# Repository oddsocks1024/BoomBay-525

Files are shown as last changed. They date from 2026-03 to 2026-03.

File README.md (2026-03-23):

# BoomBay 525
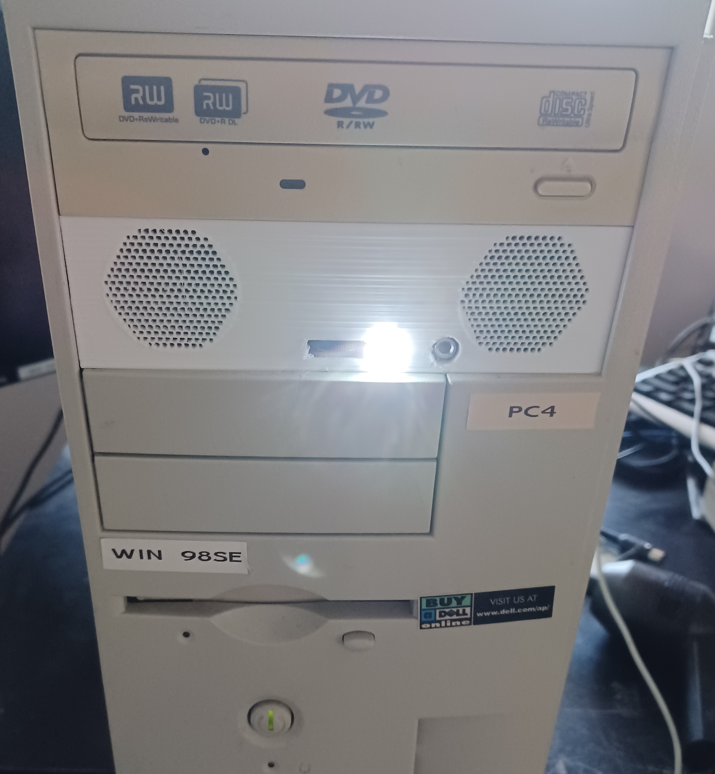
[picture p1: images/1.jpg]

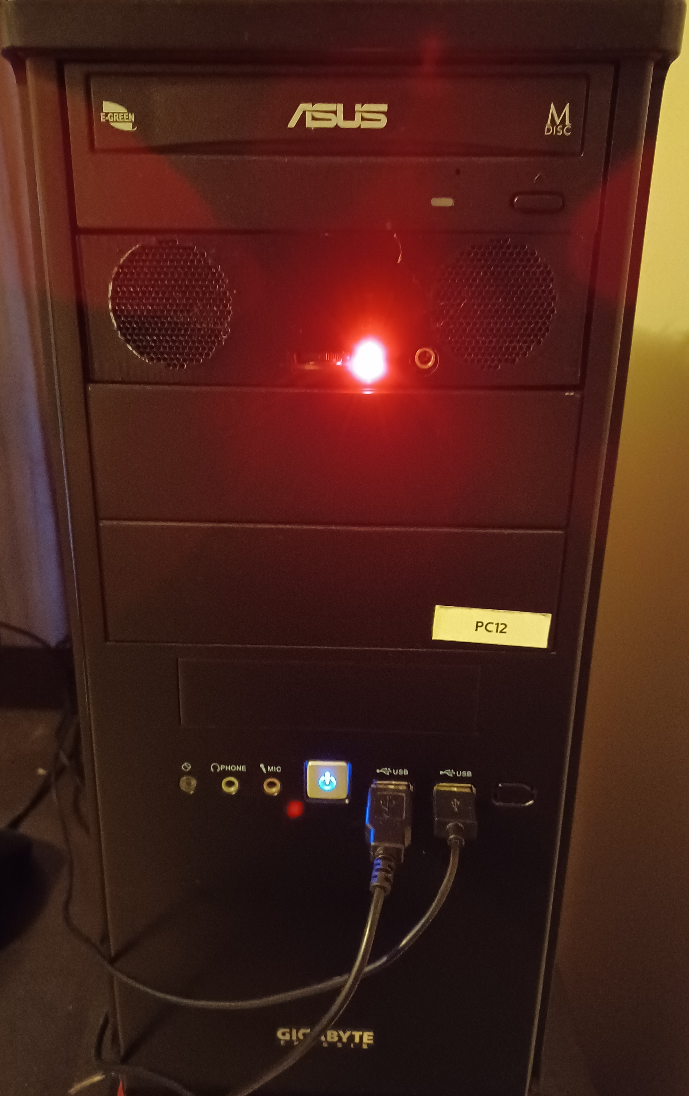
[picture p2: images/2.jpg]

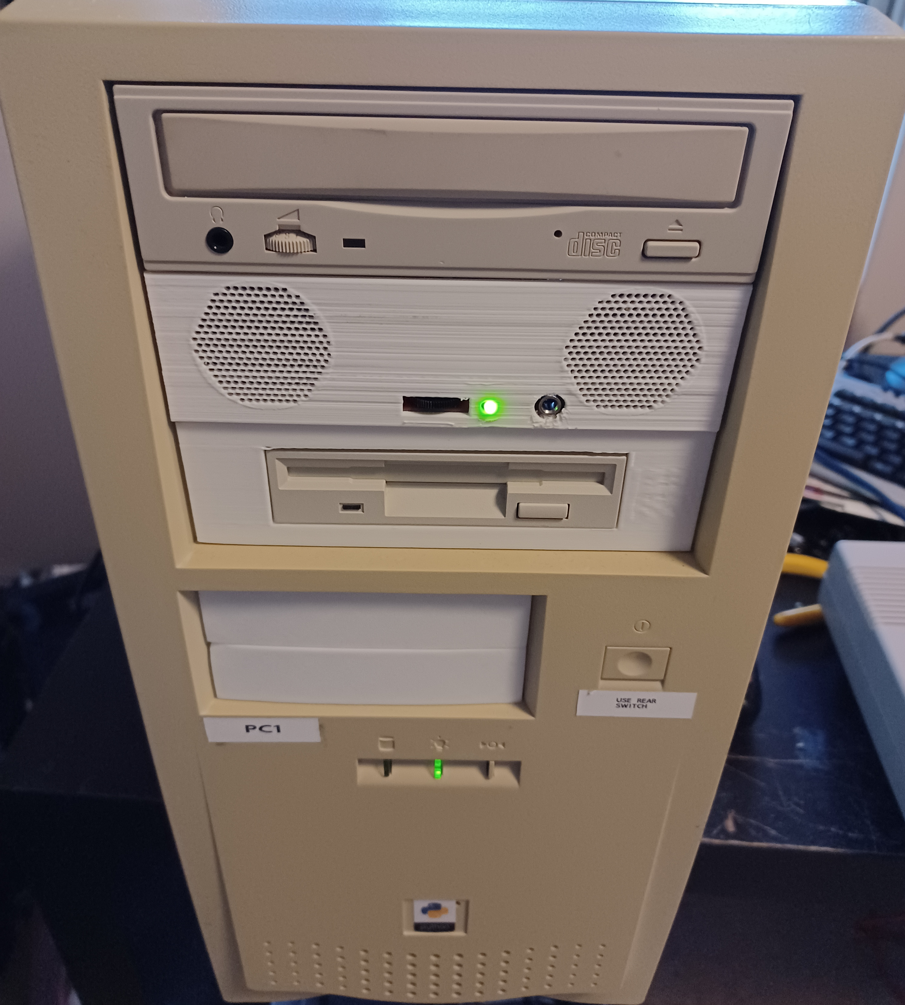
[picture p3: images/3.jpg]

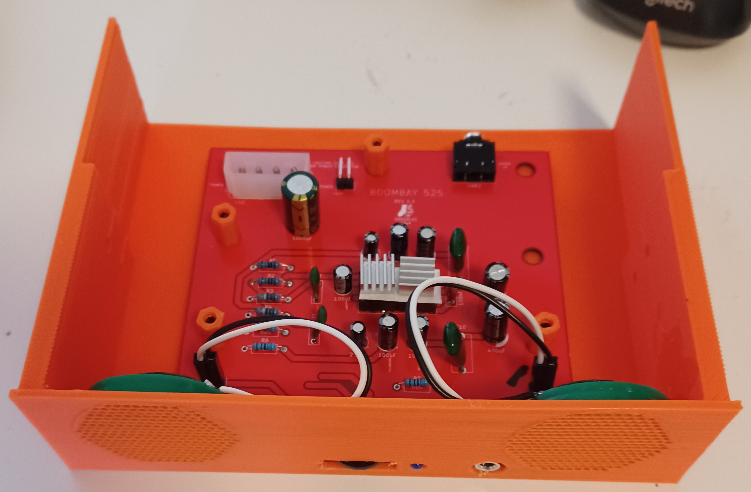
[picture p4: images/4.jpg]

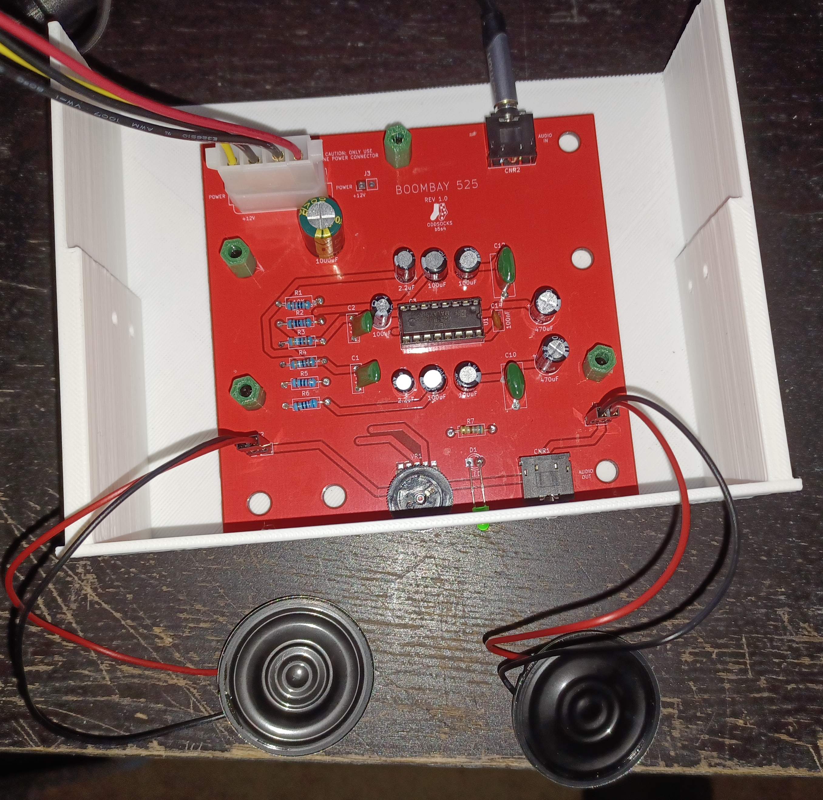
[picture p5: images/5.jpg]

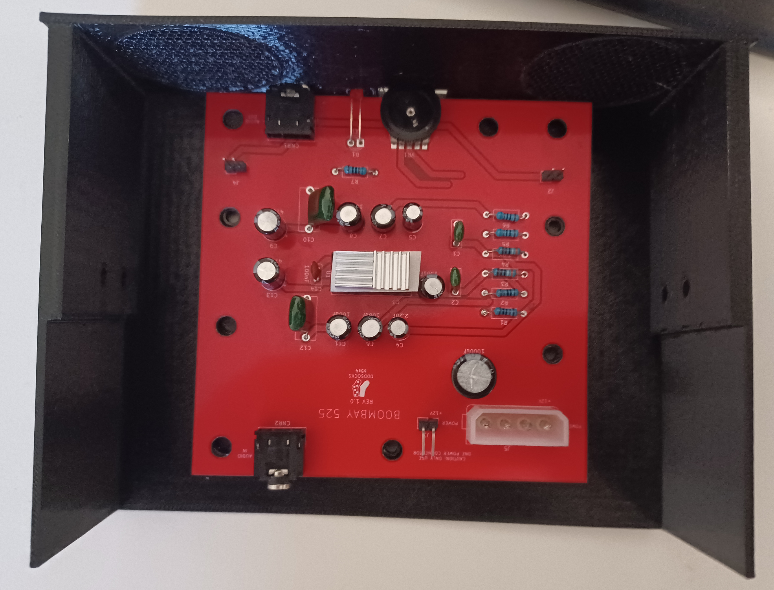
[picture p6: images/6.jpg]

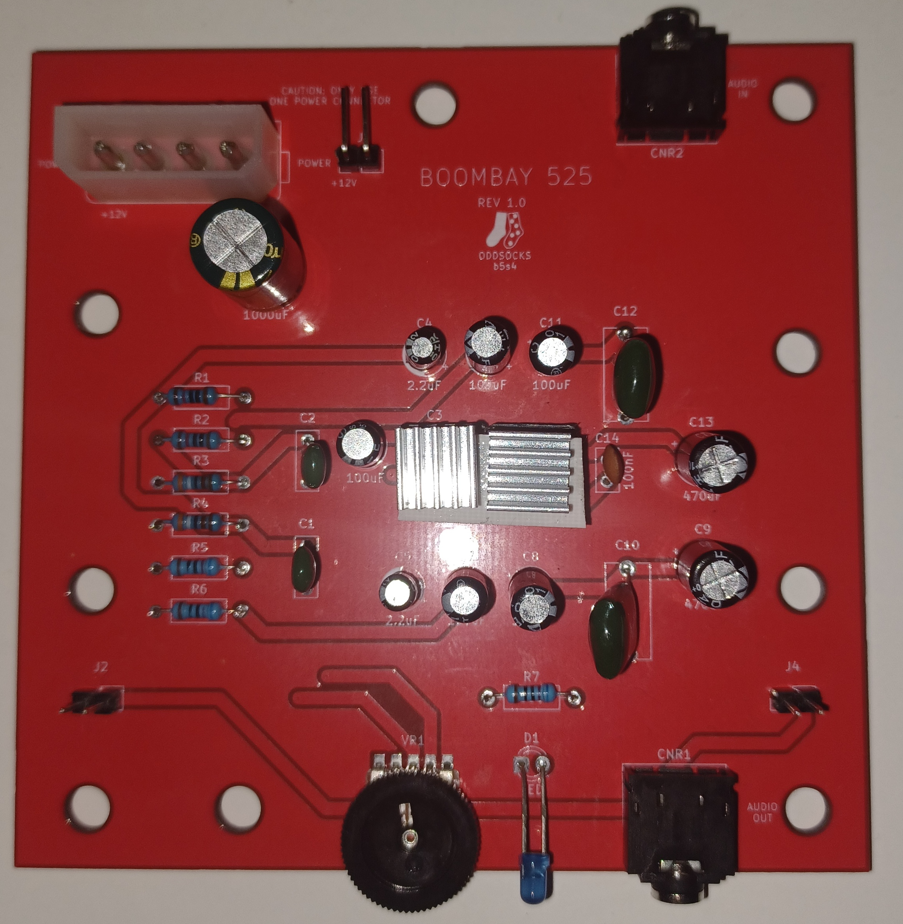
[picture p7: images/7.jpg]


## Description
A stereo speaker and amplifier for mounting in a 5.25" computer drive bay. Intended for retro-computers but could easily be used in a modern computer.

**Features**
* 3D printable 5.25" mounting case
* 2 x 36mm speakers
* Powered by a standard "hard drive" style molex connector
* Connects to your sound card's audio out
* Front volume control
* Front headphone jack socket
* Power LED

## Bill of Materials
| Qty | Component |
|:---:|---|
| 2 | 1nF Mylar/Film Capacitors |
| 2 | 150nF Mylar/Film Capacitors | 
| 5 | 100uF Electrolytic Capacitors |
| 2 | 2.2uF Electrolytic Capacitors |
| 2 | 470uF Electrolytic Capacitors |
| 1 | 1000uF Electrolytic Capacitor |
| 1 | 100nf Ceramic Capacitor |
| 2 | 10KΩ Axial Resistors |
| 2 | 3.9KΩ Axial Resistors |
| 2 | 620Ω Axial Resistors |
| 1 | 680Ω Axial Resistor |
| 1 | 3mm LED |
| 2 | 5-pin 3.5mm Audio Jack Sockets TN/T/RN/R/S |
| 1 | Male "Molex" connector (see BOM notes) |
| 1 | 5-pin 10KΩ 16mm Thumbwheel Rotary Gear Potentiometer (see BOM notes)|
| 1 | TEA2025B 16pin DIP (or compatible) |
| 2 | 36mm 8Ω Speakers (range 0.25 to 1 watt) |
| 3 | 2pin Headers (2.54mm Pitch) (see BOM notes) |
| 1 | 1 x Audio Cable with 3.5mm jacks at each end |

 * "Molex" Connector
   * The colloquilly named Molex connector is used for power. This connector is known by many names (eg MATE-N-LOK 350211), but is essentially the same power connector that was used on older hard disks and CD/DVD drives etc.
   * The right-angled version of the Molex connector would be preferred, but straight versions are perfectly usable and easier to obtain.
   * The Molex connector is not required, **if you intend to power the device by the alternate dupont connector instead.**
 * The Thumbwheel
   * This is used for volume control and these components were common on many audio devices.
   * It goes by various names, but ensure you get the 5pin variant with 16mm diameter gear.
 * 2pin Headers
   * The connector at J3 is intended for connecting a power source using a dupont connector. It is not required, **if you intend to power the device by the molex connector instead.**
   * The connectors at J2 and J4 are intended for connecting the speakers via dupont connectors. They are not required if you intend to solder the speaker wires directly to the PCB.
 * IC sockets optional.
 * The thumbwheel should be mounted on the top-side of the PCB
 * The LED should be bent over and mounted so that the 'bulb' hangs just over the PCB. See the images for more context.
 * Although the connection polarity of the speakers doesn't matter electrically, it does matter **acoustically**. Ensure both speakers use the same connection order for their wires. 
 
## 3D Printable Case
The STL files for the case are included in this repo. The PCB is designed to be mounted into this case which can than be inserted into the 5.25" drive bay of a computer. Please
also consult the images in addition to these instructions.

 * Print the case in it's normal orientation.
 * Print supports are only needed for the volume, LED and headphone cut-outs on the front. Do **not** add support for the speaker grille or side mounting screw holes.
 * Print 4 x Screw Nuts which are used for holding the PCB in place.
 * Once printed, cleanly remove the printing supports from the volume, LED and headphone cut-outs on the front of the case.
 * Insert the PCB into the case, ensuring the volume control, LED and headphone socket cleanly protrude through the cut-outs.
 * Match the 4 x PCB mounting holes with the holes in the PCB. With a good quality print, they should generally 'click' into place with a bit of a wiggle.
 * You will need 4 x 3.5mm self-tapping screws. Max length about 15mm.
 * From the base, insert a screw throught the case still it starts to protude through the PCB.
 * Hold one of the 3D printed nuts over the screw with a pair of pliers. This is to prevent the nut from spinning when turning the screw.
 * Turn the screw so that it starts to tightens, biting into the nut and holding the PCB in place. Continue until it's flush.
 * Repeat for the remaining 3 screws.
 
## Mounting in a Computer
 * Find an empty 5.25" drive bay.
 * Insert the BoomBay 525 into the drive bay.
 * Connect the Power.
 * Connect the 3.5mm audio jack cable to the audio-in on the BoomBay 525.
 * Route the other end of the cable through a convenient hole in the rear of the case. This could be:
   * An purposely designed case feature
   * A whole for a socket not used
   * A while rear a blanking-plate has been removed
   * Use a blanking plate with an appropriately size hole etc.
 * Plug the other end into the sound card audio-out.
 * Screw the case into place in the case.
 
## Support Me
Everything is freely available so you can make your own PCB and case, however if you would like to support me, please see the following links.

* [My Projects](https://projects.amiga-hardware.com) - Donate on this page
* [Order the BoomBay PCB](https://www.pcbway.com/project/shareproject/BoomBay_525_Speakers_in_your_5_25_Drive_Bay_84e0584a.html)
* [Order the BoomBay Case](https://www.pcbway.com/project/shareproject/BoomBay_525_Case_Speakers_in_your_5_25_Drive_Bay_3b4b11f0.html)

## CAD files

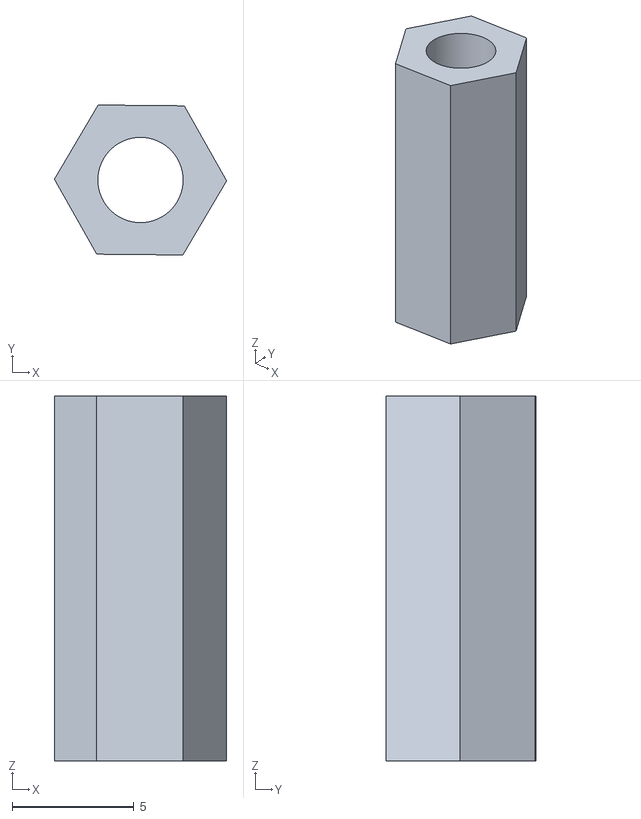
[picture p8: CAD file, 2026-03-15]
STL/BoomBay - Screw Nut.stl
7.08 x 6.17 x 15.0

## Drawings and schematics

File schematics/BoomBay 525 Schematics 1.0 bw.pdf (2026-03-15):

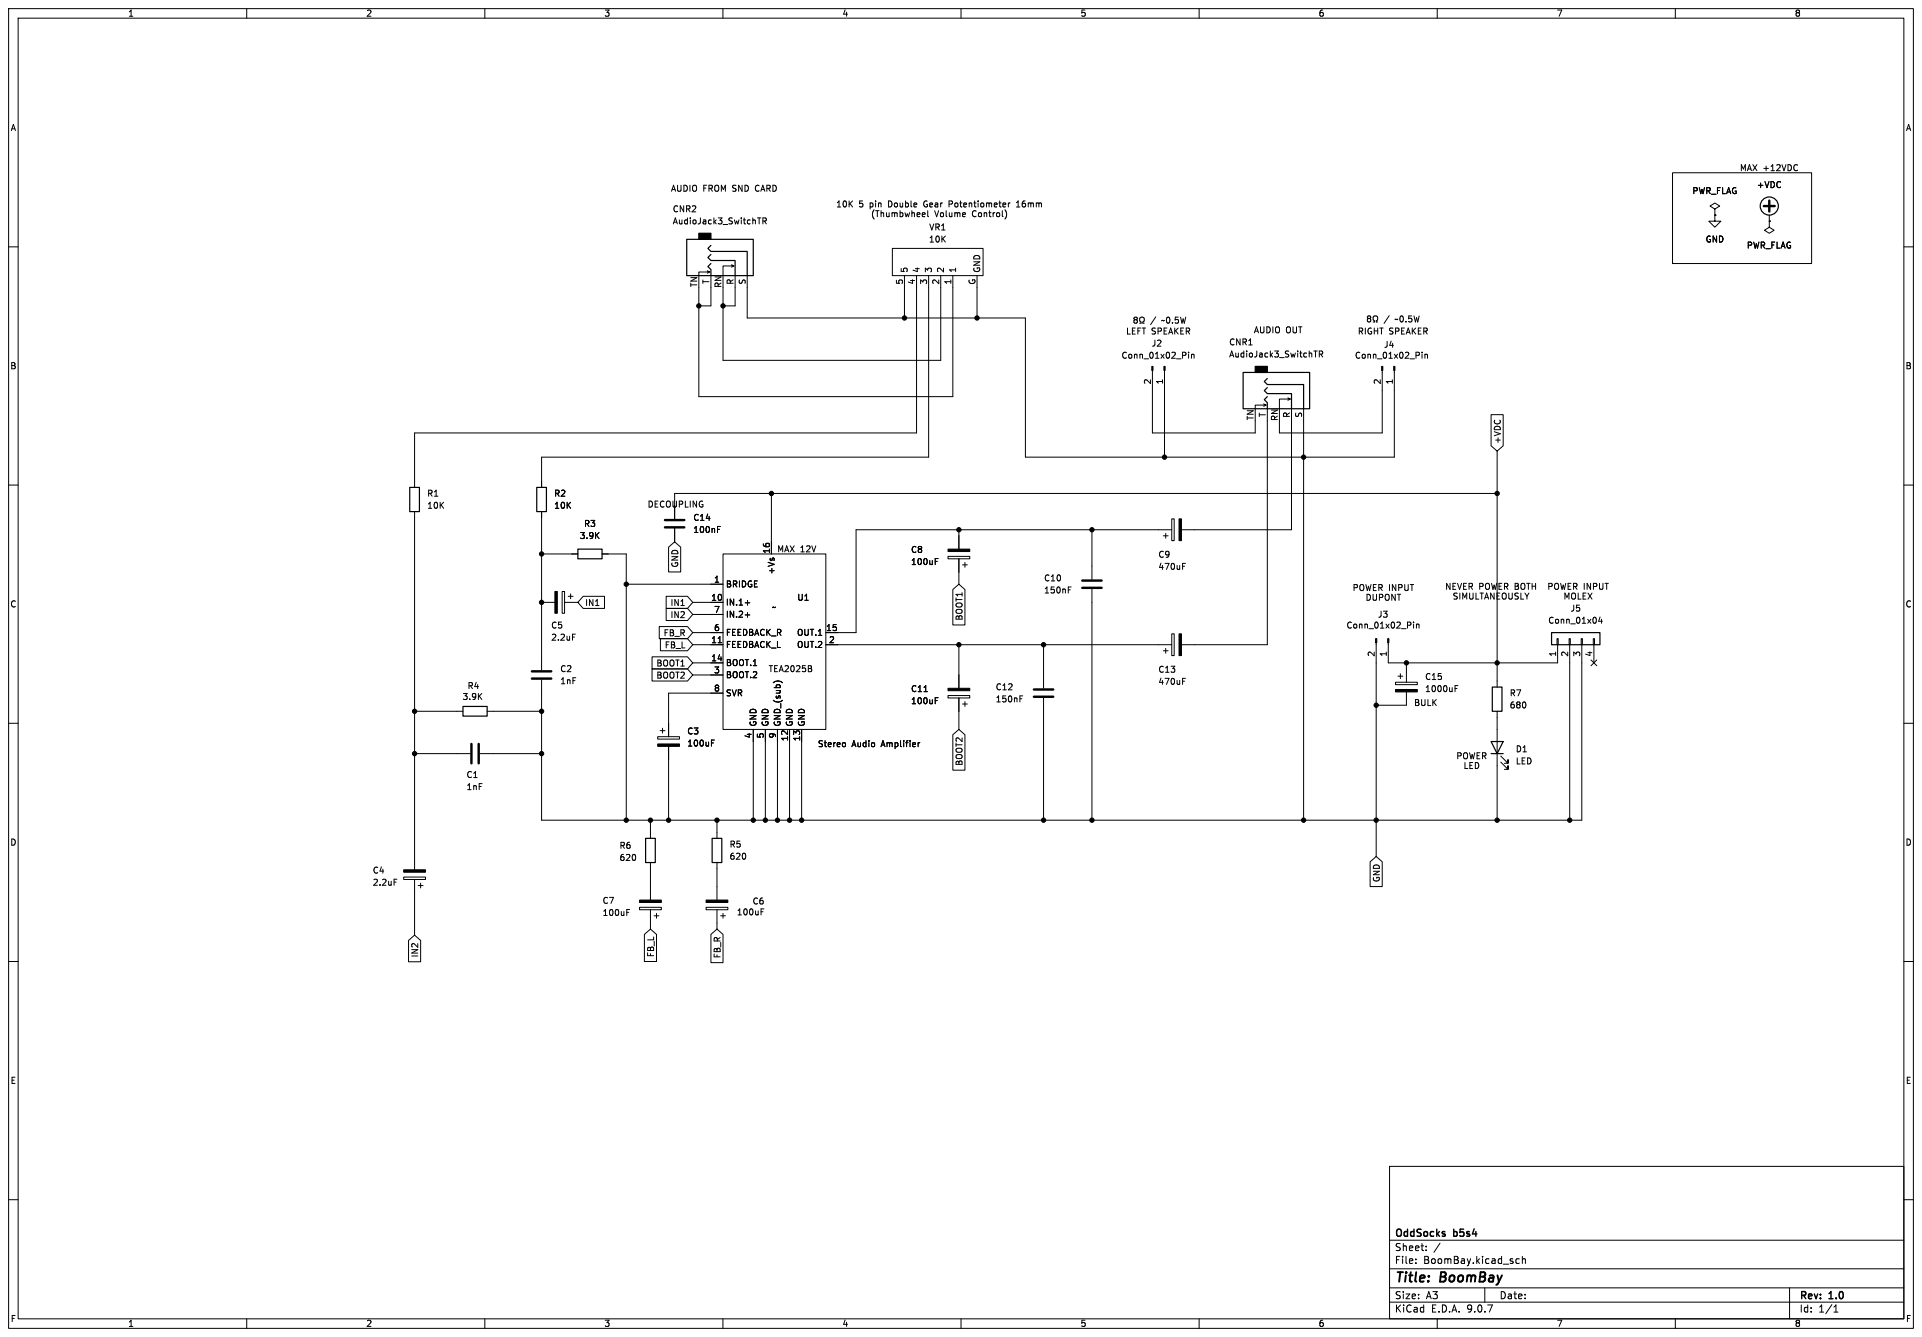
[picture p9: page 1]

5 +Vs 16 GND_(sub) 9 GND 12 GND 13 OUT.1 15 OUT.2 2 U1 ~ Stereo Audio Amplifier
J5 Conn_01x04 MAX 12V

5 +Vs 16 GND_(sub) 9 GND 12 GND 13 OUT.1 15 OUT.2 2
IN2 BOOT2 BOOT1 FB_L

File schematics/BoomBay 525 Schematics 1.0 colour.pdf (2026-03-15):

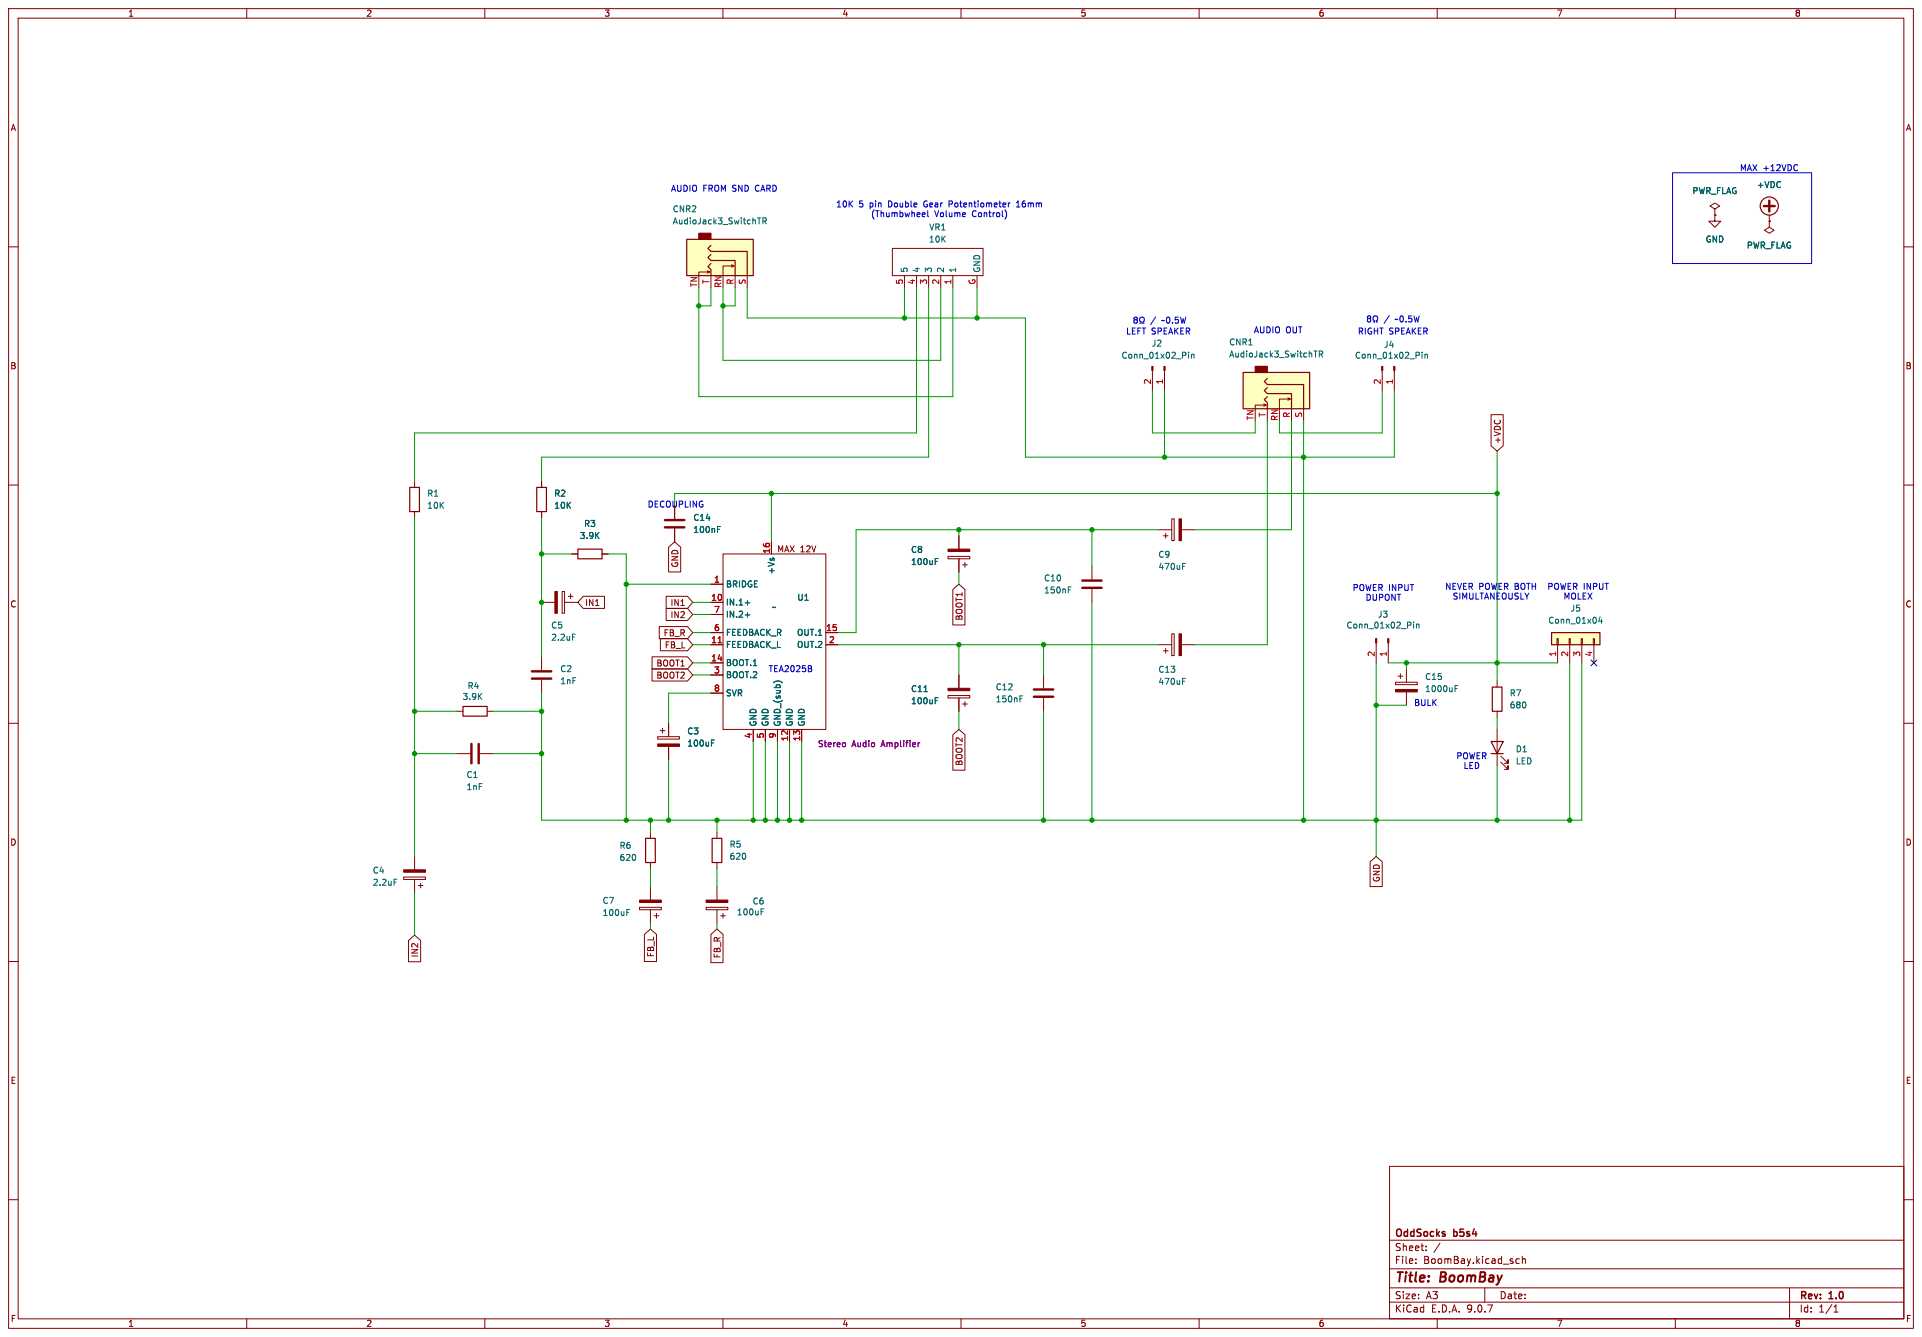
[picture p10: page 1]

AUDIO FROM SND CARD

5 +Vs 16 GND_(sub) 9 GND 12 GND 13 OUT.1 15 OUT.2 2 C3

5 +Vs 16 GND_(sub) 9 GND 12 GND 13 OUT.1 15 OUT.2 2 U1 ~ Stereo Audio Amplifier C15
